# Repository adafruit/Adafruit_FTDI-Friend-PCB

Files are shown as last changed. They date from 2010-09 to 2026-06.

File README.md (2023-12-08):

# Adafruit FTDI Friend

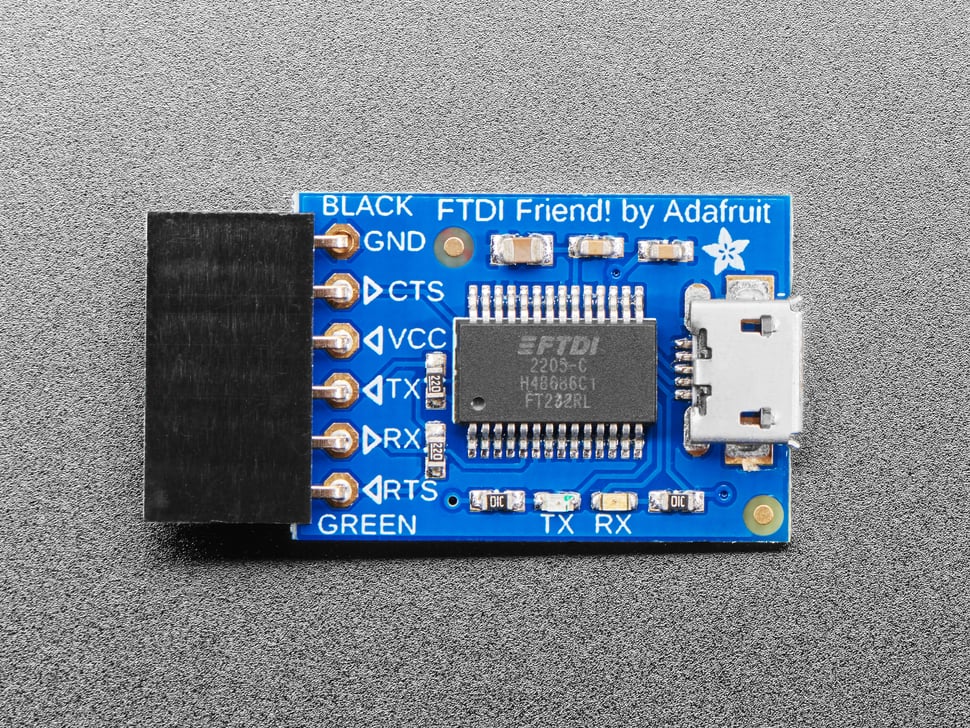
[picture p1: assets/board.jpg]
<a href="http://www.adafruit.com/products/284"><br/>Click here to purchase one from the Adafruit shop</a>

Long gone are the days of parallel ports and serial ports. Now the USB port reigns supreme! But USB is hard, and you just want to transfer your every-day serial data from a microcontroller to computer. What now? Enter the FTDI Friend!

The FTDI Friend is a tweaked out FTDI FT232RL chip adapter. Sure, like the well-known FTDI cable, it can provide power to your project and there are 4 signal lines for sending data back and forth. But the Friend can do much more! For example, you can change the signal and power lines to be either 3.3V or 5V. Arduino-derivatives and XBees use the RTS line for programming but what if you need that DTR line? It's there for you.
By default, we've set it up so that it matches our FTDI cables. The 6th pin is RTS (as of Arduino IDE v18 this will work perfectly for uploading to 'inos), the power wire is +5V and the signal levels are 3.3V (they are 5V compliant, and should work in the vast majority of 3.3V and 5V signal systems).

And of course, we include __a little extra__ - in this case its the extra-long headers that you can use to plug it into a breadboard. There are also blinkies, 2 red & green LEDs __already on the board__ that pulse when serial is sent or received.

Revision History:

* As of December 5, 2023 - We've updated this board with a micro USB-B connector as well as used Adafruit Pinguin to make a lovely silkscreen.

### License

Adafruit invests time and resources providing this open source design, please support Adafruit and open-source hardware by purchasing products from [Adafruit](https://www.adafruit.com)!

Designed by Limor Fried/Ladyada for Adafruit Industries.

Creative Commons Attribution/Share-Alike, all text above must be included in any redistribution. See license.txt for additional details.

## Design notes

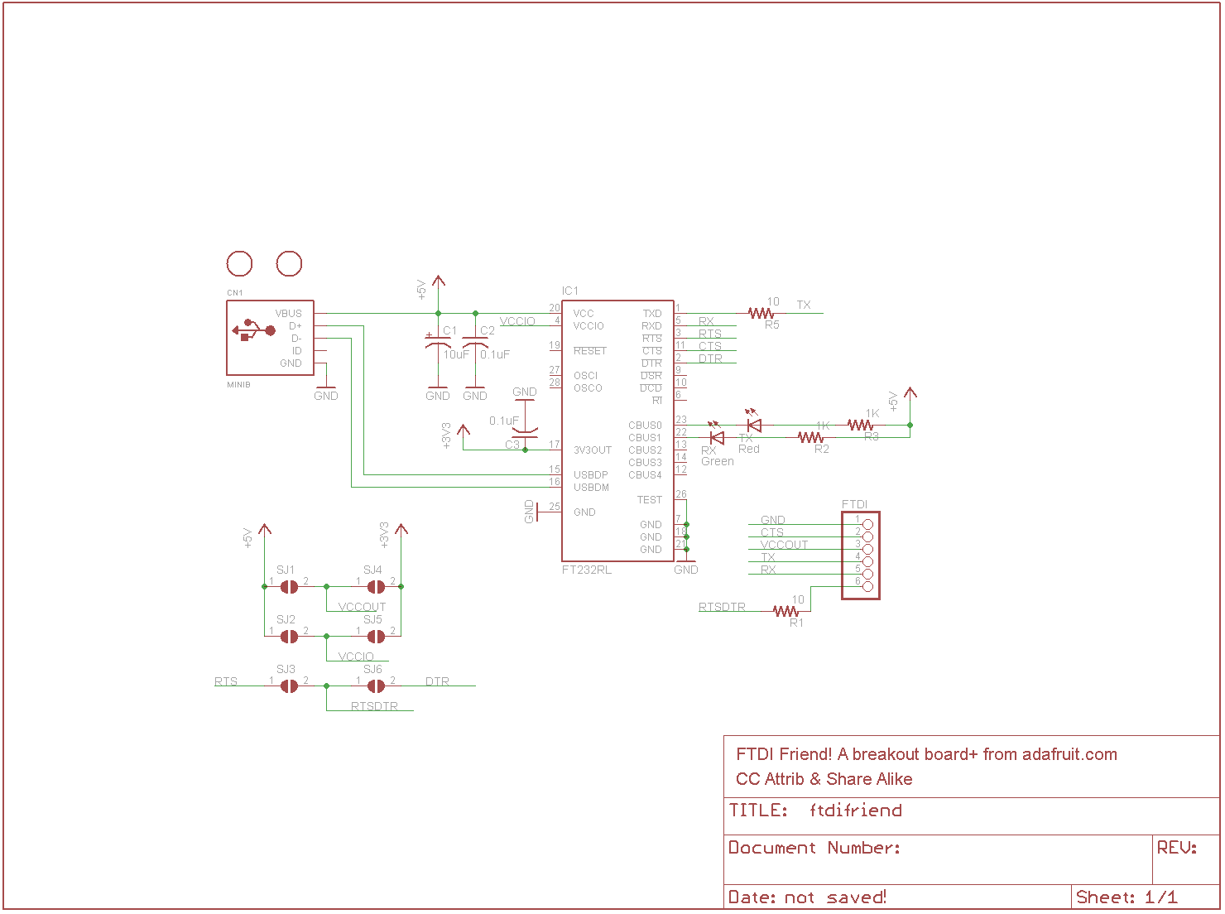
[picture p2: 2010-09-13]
ftdifriendsch.png

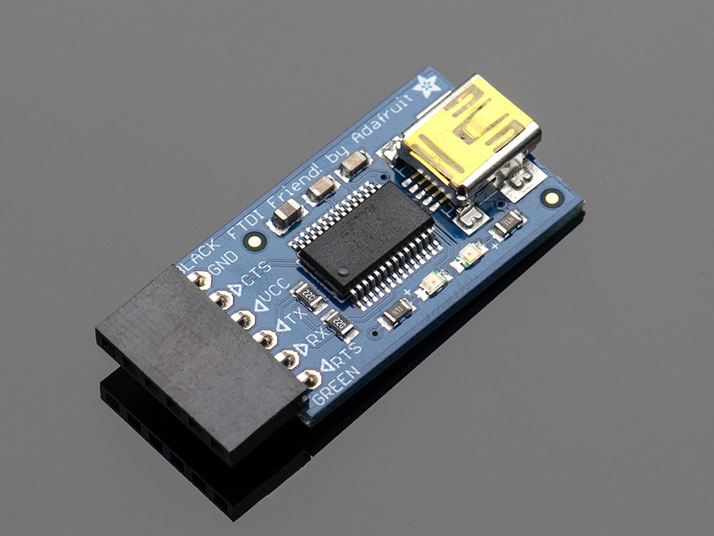
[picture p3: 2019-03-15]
assets/revA.jpg

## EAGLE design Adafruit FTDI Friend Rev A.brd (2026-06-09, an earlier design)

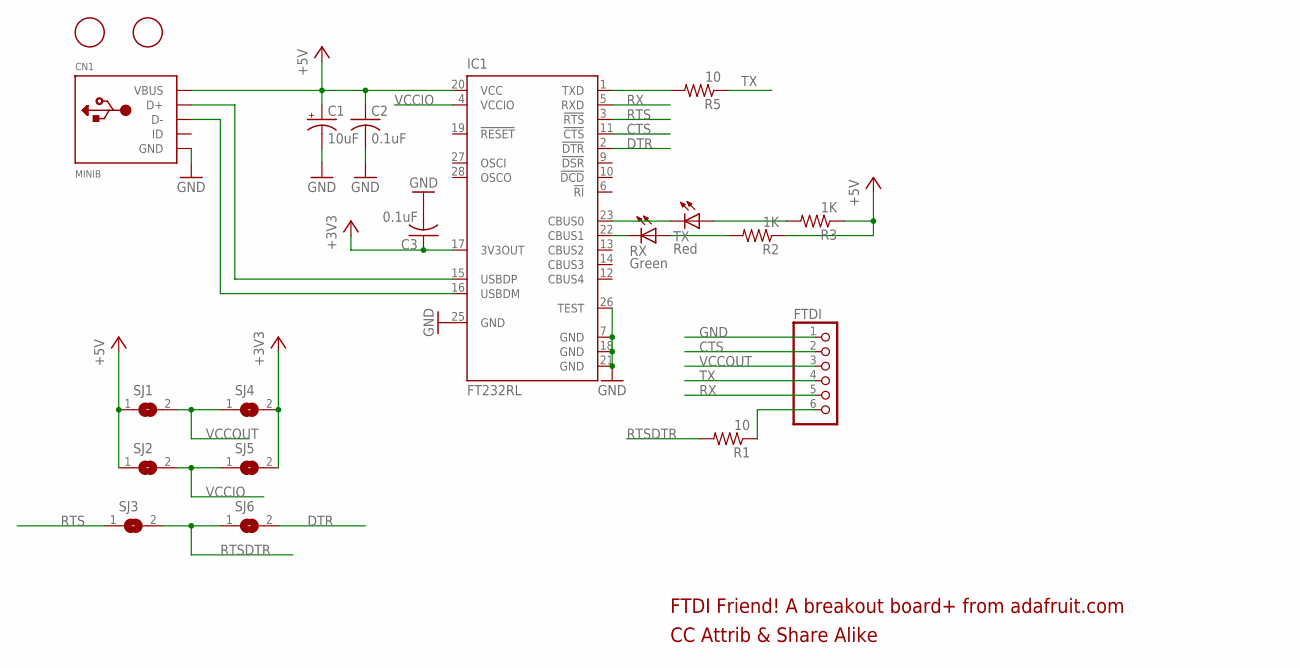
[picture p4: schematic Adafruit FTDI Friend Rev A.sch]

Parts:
C1: 10uF; A/3216-18R
C2, C3: 0.1uF; C0805K
CN1: MINIB; USB-MINIB
FTDI: PINHD-1X6CB; 1X06-CLEANBIG
IC1: FT232RL; SSOP28
R1, R5: 10; R0805
R2, R3: 1K; R0805
RX: Green; CHIP-LED0805
SJ1, SJ2, SJ3, SJ4, SJ5, SJ6: SJ
TX: Red; CHIP-LED0805
U$1, U$2: FIDUCIAL; FIDUCIAL_1MM

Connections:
+3V3: C3.1, IC1.17 (3V3OUT), SJ4.2, SJ5.2
+5V: C1.+, C2.1, CN1.VBUS, IC1.20 (VCC), R2.1, R3.1, SJ1.1, SJ2.1
CTS: FTDI.2, IC1.11 (!CTS)
DTR: IC1.2 (!DTR), SJ6.2
GND: C1.-, C2.2, C3.2, CN1.GND, FTDI.1, IC1.7 (GND), IC1.18 (GND), IC1.21 (GND), IC1.25 (GND), IC1.26 (TEST)
unnamed: FTDI.6, R1.1
unnamed: CN1.D+, IC1.15 (USBDP)
unnamed: CN1.D-, IC1.16 (USBDM)
unnamed: IC1.1 (TXD), R5.2
unnamed: IC1.23 (CBUS0), TX.C
unnamed: IC1.22 (CBUS1), RX.C
unnamed: R2.2, RX.A
unnamed: R3.2, TX.A
RTS: IC1.3 (!RTS), SJ3.1
RTSDTR: R1.2, SJ3.2, SJ6.1
RX: FTDI.5, IC1.5 (RXD)
TX: FTDI.4, R5.1
VCCIO: IC1.4 (VCCIO), SJ2.2, SJ5.1
VCCOUT: FTDI.3, SJ1.2, SJ4.1

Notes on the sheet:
CC Attrib & Share Alike
FTDI Friend! A breakout board+ from adafruit.com

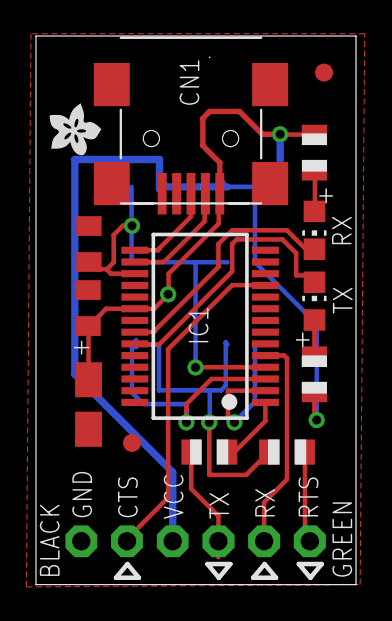
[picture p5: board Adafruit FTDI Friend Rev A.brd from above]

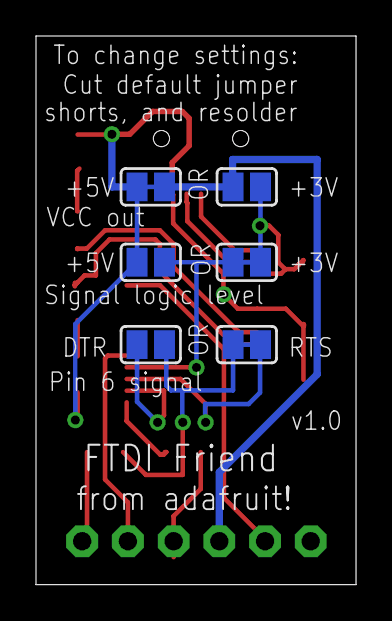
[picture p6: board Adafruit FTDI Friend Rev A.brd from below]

Board: 2 copper layers, 17.8 x 30.5 mm, 21 parts (6 on the bottom side), 19 nets.

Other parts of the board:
U$3: ADAFRUIT200MIL

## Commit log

2010-09-13 v1.0 for release!
    [ftdifriend.brd, ftdifriend.sch]
2010-09-13 Schematic image
2023-12-08 adding rev B files
    [Adafruit FTDI Friend Rev A.brd, Adafruit FTDI Friend Rev A.sch, Adafruit FTDI Friend Rev B.brd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]
2026-06-03 update file format to XML
    [Adafruit FTDI Friend Rev A.brd, Adafruit FTDI Friend Rev A.sch]
